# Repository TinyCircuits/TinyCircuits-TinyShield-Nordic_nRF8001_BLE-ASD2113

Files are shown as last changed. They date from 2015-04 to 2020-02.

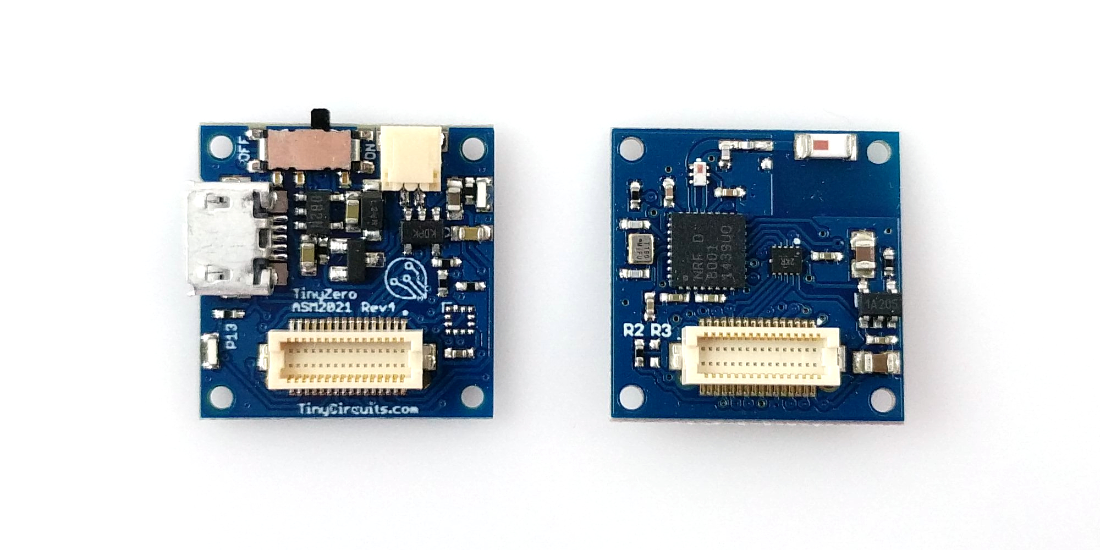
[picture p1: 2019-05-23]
images/ASD2113-R-Tutorial-Image-02.jpg

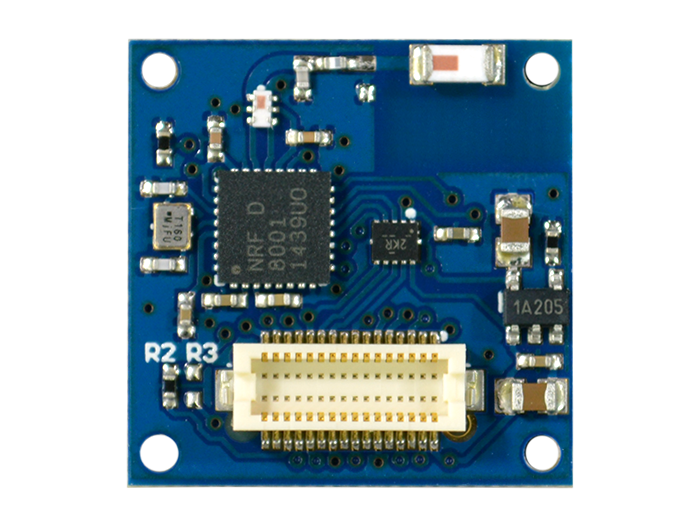
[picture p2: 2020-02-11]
images/ASD2113-R-Tutorial-Image-01.png

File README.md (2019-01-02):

# TinyCircuits TinyShield Nordic nRF8001 Bluetooth LE Board
# ASD2113 Rev3

The design files are located under design_files/ for the TinyCircuits ASD2113 Rev3 PCB.  This is a TinyShield board that has a Nordic Semiconductor nRF8001 Bluetooth Low Energy (or Smart) 4.0 chipset, local power supply and level shifters to connect between the TinyDuino and the Bluetooth LE Module. 

Format is in Cadsoft Eagle format - Eagle version 6.2 was used for the original design.

For more infomation on this, check out the product page at TinyCircuits.com: https://tinycircuits.com/collections/communication/products/bluetooth-low-energy-nordic-tinyshield

# License:

Design by TinyCircuits.
All design files are released under the Creative Commons Attribution Share-Alike 3.0 License, see the following link for details: http://creativecommons.org/licenses/by-sa/3.0

All text above must be included in any redistribution or derived design

This project uses designs and concepts developed as part of the Arduino project and the LilyPad project.  The TinyCircuits design files themselves (schematics, PCB and libraries) are not directly derived from these works' design files and have been created new, however the concepts and basic architecture behind the TinyDuino and TinyLily products are derived and we thank the hard work of the organizations below for their contributions to open-source hardware:
  
Original Arduino Uno Design by Team Arduino

LilyPad Arduino Design by Leah Buechley and Sparkfun Electronics

Please support the open-source hardware community

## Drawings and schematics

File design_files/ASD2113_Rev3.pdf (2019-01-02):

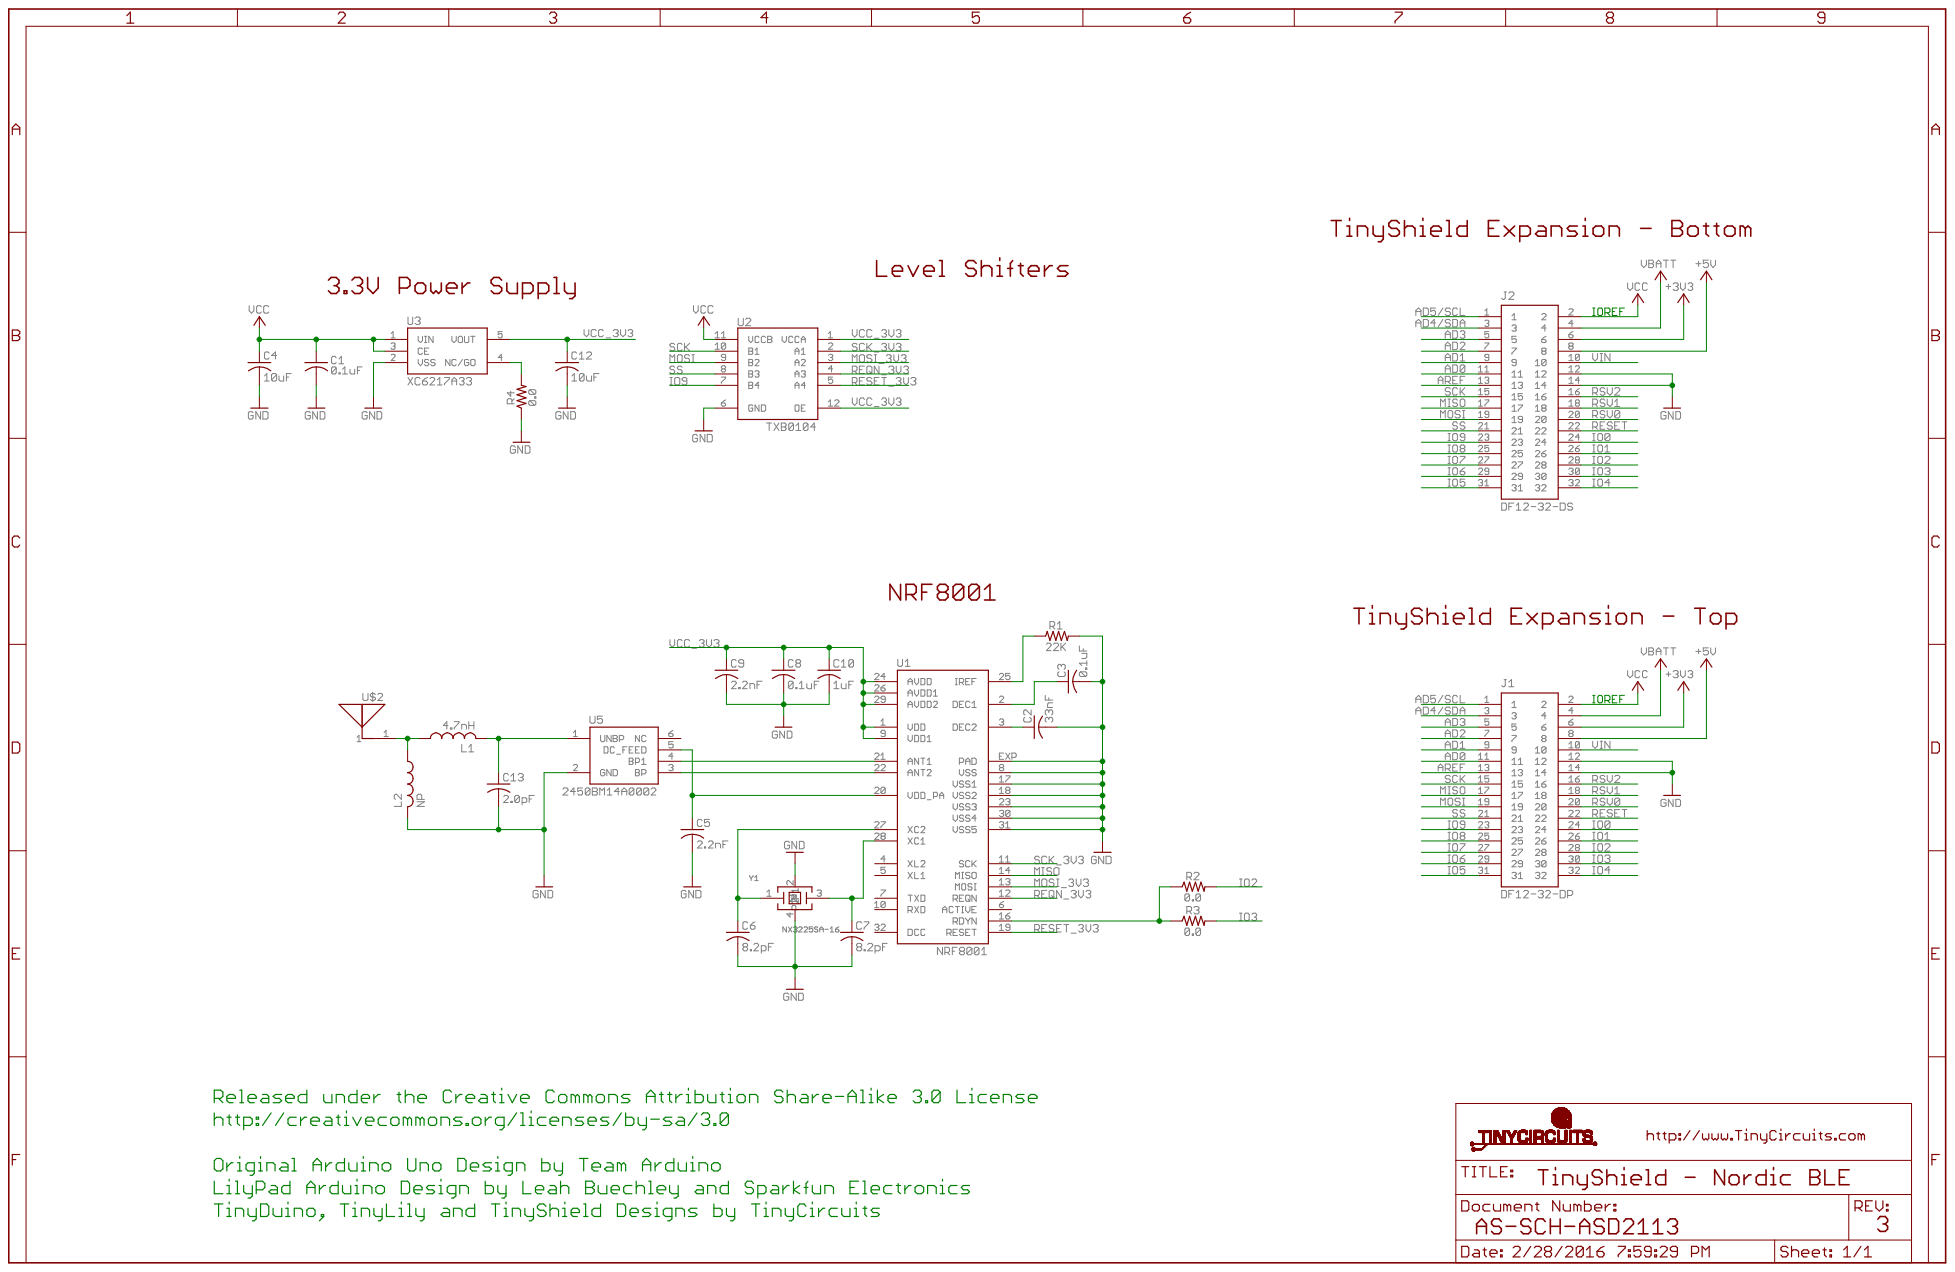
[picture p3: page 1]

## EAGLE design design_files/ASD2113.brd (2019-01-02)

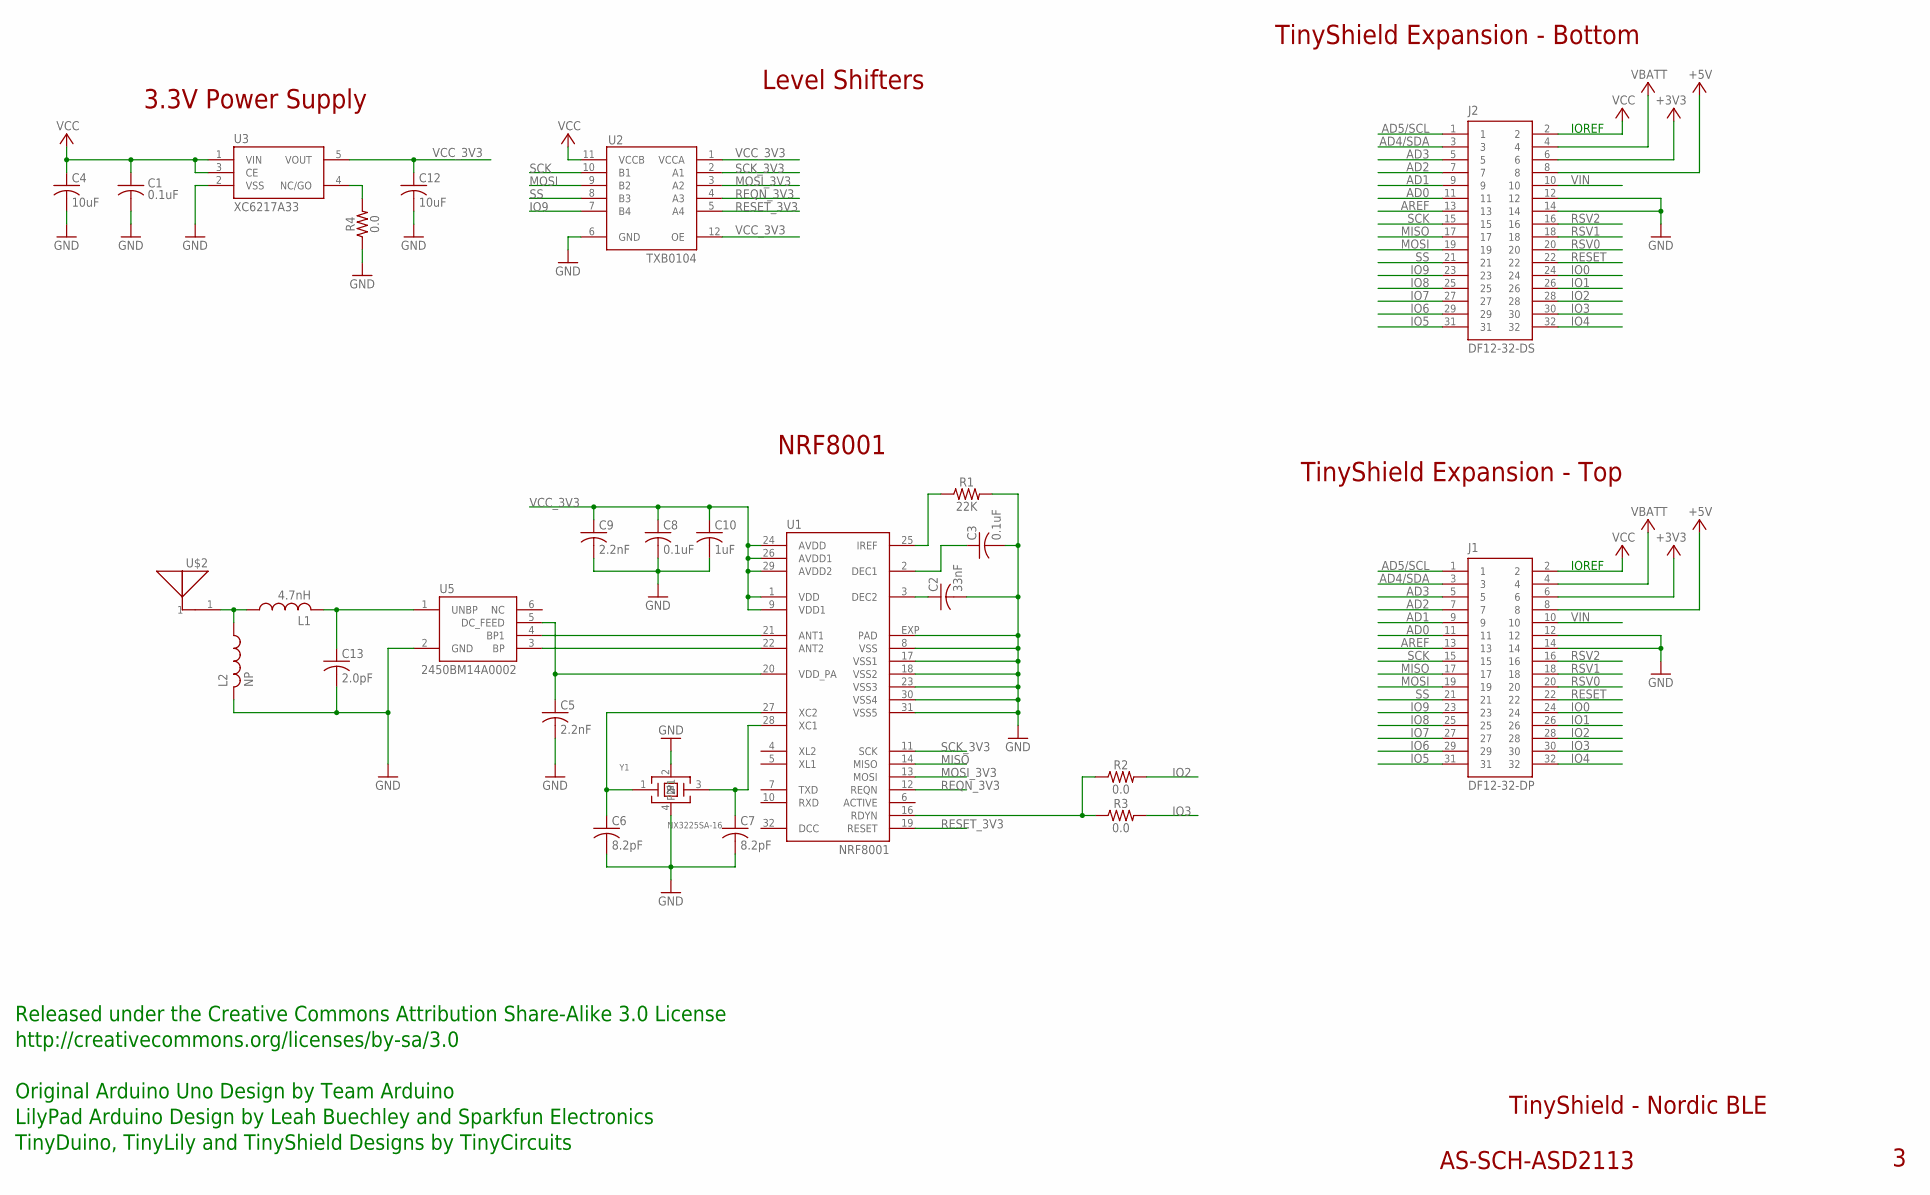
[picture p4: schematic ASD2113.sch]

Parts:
C1: 0.1uF; C0402; PARTNO AS-ITM-00008
C2: 33nF; C0402; PARTNO AS-ITM-00248
C3, C8: 0.1uF; C0402
C4, C12: 10uF; C0805; PARTNO AS-ITM-00045
C5, C9: 2.2nF; C0402
C6, C7: 8.2pF; C0402; PARTNO AS-ITM-00247
C10: 1uF; C0402
C13: 2.0pF; C0402; PARTNO AS-ITM-00245
J1: DF12-32-DP; PARTNO AS-ITM-00015
J2: DF12-32-DS; PARTNO AS-ITM-00012
L1: 4.7nH; C0402; PARTNO AS-ITM-00246
L2: NP; C0402
R1: 22K; 0402
R2, R3: 0.0; 0402; PARTNO AS-ITM-00076
R4: 0.0; 0402
U1: NRF8001; ATMEL_QFN32
U2: TXB0104; UQFN-12
U3: XC6217A33; SOT-25; PARTNO AS-ITM-00249
U5: 2450BM14A0002
U$2: AS-ITM-00132; 2450AT18A100; PARTNO AS-ITM-00132
Y1: NX3225SA-16; ABM11; PARTNO AS-ITM-00228

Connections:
+3V3: J1.6, J2.6
+5V: J1.8, J2.8
AD0: J1.11, J2.11
AD1: J1.9, J2.9
AD2: J1.7, J2.7
AD3: J1.5, J2.5
AD4/SDA: J1.3, J2.3
AD5/SCL: J1.1, J2.1
AREF: J1.13, J2.13
GND: C1.2, C2.2, C3.2, C4.2, C5.2, C6.2, C7.2, C8.2, C9.2, C10.2, C12.2, C13.2, J1.12, J1.14, J2.12, J2.14, L2.2, R1.2, R4.1, U1.8 (VSS), U1.17 (VSS1), U1.18 (VSS2), U1.23 (VSS3), U1.30 (VSS4), U1.31 (VSS5), U1.EXP (PAD), U2.6 (GND), U3.2 (VSS), U5.2 (GND), Y1.2, Y1.4 (P1)
IO0: J1.24, J2.24
IO1: J1.26, J2.26
IO2: J1.28, J2.28, R2.2
IO3: J1.30, J2.30, R3.2
IO4: J1.32, J2.32
IO5: J1.31, J2.31
IO6: J1.29, J2.29
IO7: J1.27, J2.27
IO8: J1.25, J2.25
IO9: J1.23, J2.23, U2.7 (B4)
MISO: J1.17, J2.17, U1.14 (MISO)
MOSI: J1.19, J2.19, U2.9 (B2)
MOSI_3V3: U1.13 (MOSI), U2.3 (A2)
unnamed: R1.1, U1.25 (IREF)
unnamed: C6.1, U1.27 (XC2), Y1.1
unnamed: C13.1, L1.2, U5.1 (UNBP)
unnamed: C3.1, U1.2 (DEC1)
unnamed: C2.1, U1.3 (DEC2)
unnamed: U1.22 (ANT2), U5.3 (BP)
unnamed: U1.21 (ANT1), U5.4 (BP1)
unnamed: C5.1, U1.20 (VDD_PA), U5.5 (DC_FEED)
unnamed: C7.1, U1.28 (XC1), Y1.3 (2)
unnamed: L1.1, L2.1, U$2.1
unnamed: R4.2, U3.4 (NC/GO)
RDYN: R2.1, R3.1, U1.16 (RDYN)
REQN_3V3: U1.12 (REQN), U2.4 (A3)
RESET: J1.22, J2.22
RESET_3V3: U1.19 (RESET), U2.5 (A4)
RSV0: J1.20, J2.20
RSV1: J1.18, J2.18
RSV2: J1.16, J2.16
SCK: J1.15, J2.15, U2.10 (B1)
SCK_3V3: U1.11 (SCK), U2.2 (A1)
SS: J1.21, J2.21, U2.8 (B3)
VBATT: J1.4, J2.4
VCC: C1.1, C4.1, J1.2, J2.2, U2.11 (VCCB), U3.1 (VIN), U3.3 (CE)
VCC_3V3: C8.1, C9.1, C10.1, C12.1, U1.1 (VDD), U1.9 (VDD1), U1.24 (AVDD), U1.26 (AVDD1), U1.29 (AVDD2), U2.1 (VCCA), U2.12 (OE), U3.5 (VOUT)
VIN: J1.10, J2.10

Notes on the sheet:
TinyShield Expansion - Bottom
TinyShield - Nordic BLE
AS-SCH-ASD2113
TinyShield Expansion - Top
IOREF
Released under the Creative Commons Attribution Share-Alike 3.0 License
http://creativecommons.org/licenses/by-sa/3.0
LilyPad Arduino Design by Leah Buechley and Sparkfun Electronics
TinyDuino, TinyLily and TinyShield Designs by TinyCircuits
Original Arduino Uno Design by Team Arduino
3.3V Power Supply
NRF8001
Level Shifters

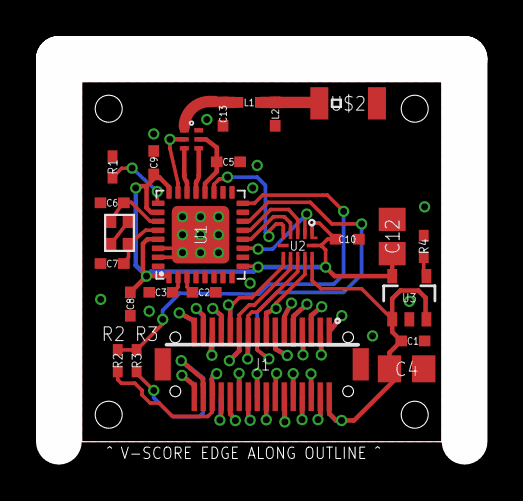
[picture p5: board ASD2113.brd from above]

Board: 2 copper layers, 20.0 x 20.0 mm, 27 parts (1 on the bottom side), 48 nets.

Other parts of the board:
U$1: DOCFIELD-TINYCIRCUITS-PCB

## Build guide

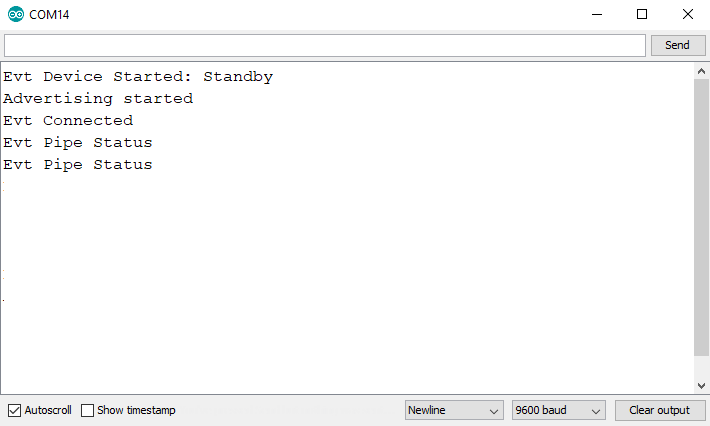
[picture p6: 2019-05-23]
images/ASD2113-R-Tutorial-Image-10.png

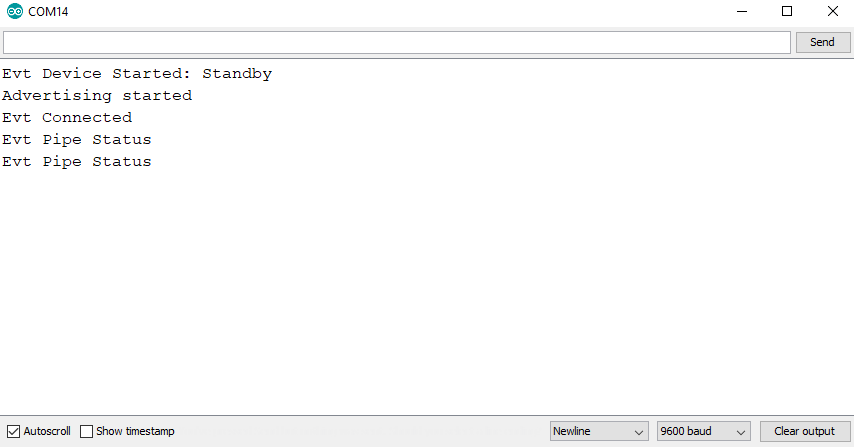
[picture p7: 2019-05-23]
images/ASD2113-R-Tutorial-Image-06.png

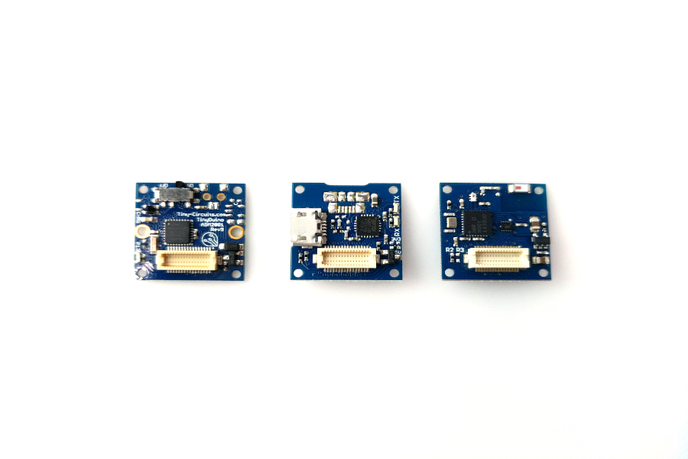
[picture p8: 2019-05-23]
images/ASD2113-R-Tutorial-Image-02.png

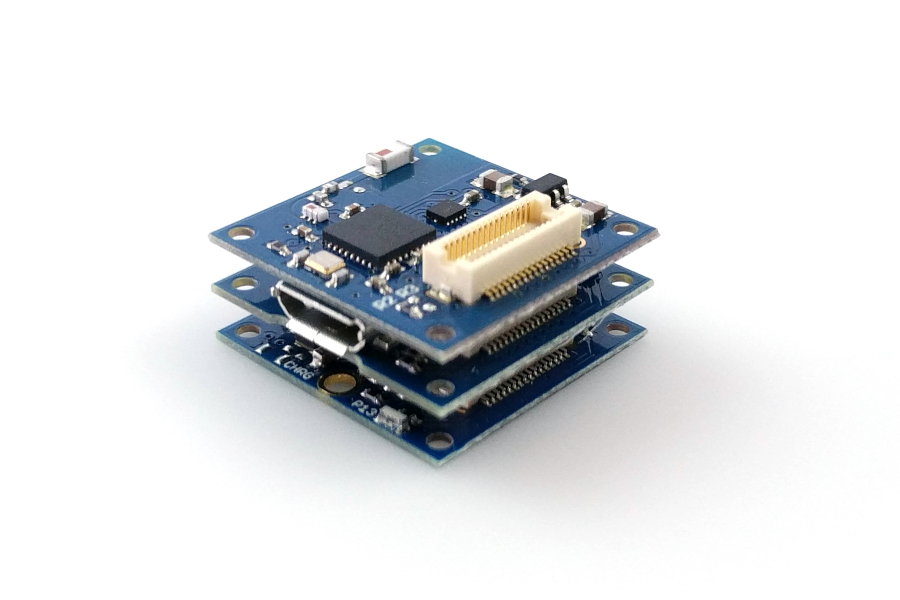
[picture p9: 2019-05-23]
images/ASD2113-R-Tutorial-Image-03.png

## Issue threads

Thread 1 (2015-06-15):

404 - PAGE NOT FOUND

malayli, 2015-06-15:
Hello,

This link returns a 404 error:

https://tiny-circuits.com/tiny-shield-nrf8001-bluetooth-low-energy.html

Best Regards,

Malik ALAYLI

TinyCircuits, 2015-06-15:
Thanks for noticing this, the link is fixed now.

malayli, 2015-06-19:
Ok I close the issue :)

Closed 2015-06-19.

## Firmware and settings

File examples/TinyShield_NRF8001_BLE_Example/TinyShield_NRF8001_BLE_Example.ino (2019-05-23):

/*
  TinyCircuits NRF8001 UART Example Sketch

  This demo sets up the NRF8001 for Nordic's BLE virtual UART connection, and
  can pass data between the Arduino serial monitor and Nordic nRF UART V2.0 app
  or another compatible BLE terminal. Now supports TinyScreen+/SAMD21 boards.

  Written 27 May 2016
  By Ben Rose
  Modified 07 January 2019
  By Hunter Hykes

  https://TinyCircuits.com
*/


#if defined(ARDUINO_ARCH_SAMD)
  #define SerialMonitorInterface SerialUSB
#else
  #define SerialMonitorInterface Serial
#endif

#define BLE_DEBUG true

#include <SPI.h>
#include "lib_aci.h"
#include "aci_setup.h"
#include "uart_over_ble.h"
#include "services.h"

uint8_t ble_rx_buffer[21];
uint8_t ble_rx_buffer_len = 0;
uint8_t ble_connection_state = false;

void setup(void)
{
  SerialMonitorInterface.begin(9600);
//  while (!SerialMonitorInterface);//Optional- On TinyScreen+/SAMD21 boards this will block until the serial monitor is opened
  delay(1000);
  BLEsetup();
}

void loop() {
  aci_loop();//Process any ACI commands or events from the NRF8001- main BLE handler, must run often. Keep main loop short.
  if (ble_rx_buffer_len) {//Check if data is available
    SerialMonitorInterface.print(ble_rx_buffer_len);
    SerialMonitorInterface.print(" : ");
    SerialMonitorInterface.println((char*)ble_rx_buffer);
    ble_rx_buffer_len = 0;//clear afer reading
  }
  if (SerialMonitorInterface.available()) {//Check if serial input is available to send
    delay(50);//should catch full input
    uint8_t sendBuffer[21];
    uint8_t sendLength = 0;
    while (SerialMonitorInterface.available() && sendLength < 19) {
      sendBuffer[sendLength] = SerialMonitorInterface.read();
      sendLength++;
    }
    if (SerialMonitorInterface.available()) {
      SerialMonitorInterface.print(F("Input truncated, dropped: "));
      while (SerialMonitorInterface.available()) {
        SerialMonitorInterface.write(SerialMonitorInterface.read());
      }
      SerialMonitorInterface.println();
    }
    sendBuffer[sendLength] = '\0'; //Terminate string
    sendLength++;
    if (!lib_aci_send_data(PIPE_UART_OVER_BTLE_UART_TX_TX, (uint8_t*)sendBuffer, sendLength))
    {
      SerialMonitorInterface.println(F("TX dropped!"));
    }
  }

}

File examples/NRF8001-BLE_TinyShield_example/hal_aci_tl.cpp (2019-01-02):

/* Copyright (c) 2014, Nordic Semiconductor ASA
 *
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
 * THE SOFTWARE IS PROVIDED "AS IS", WITHOUT WARRANTY OF ANY KIND, EXPRESS OR
 * IMPLIED, INCLUDING BUT NOT LIMITED TO THE WARRANTIES OF MERCHANTABILITY,
 * FITNESS FOR A PARTICULAR PURPOSE AND NONINFRINGEMENT. IN NO EVENT SHALL THE
 * AUTHORS OR COPYRIGHT HOLDERS BE LIABLE FOR ANY CLAIM, DAMAGES OR OTHER
 * LIABILITY, WHETHER IN AN ACTION OF CONTRACT, TORT OR OTHERWISE, ARISING FROM,
 * OUT OF OR IN CONNECTION WITH THE SOFTWARE OR THE USE OR OTHER DEALINGS IN THE
 * SOFTWARE.
 */

/** @file
@brief Implementation of the ACI transport layer module
*/

#include <SPI.h>
#include "hal_platform.h"
#include "hal_aci_tl.h"
#include "aci_queue.h"
#if ( !defined(__SAM3X8E__) && !defined(__PIC32MX__) && !defined(ARDUINO_ARCH_SAMD))
#include <avr/sleep.h>
#endif
/*
PIC32 supports only MSbit transfer on SPI and the nRF8001 uses LSBit
Use the REVERSE_BITS macro to convert from MSBit to LSBit
The outgoing command and the incoming event needs to be converted
*/
//Board dependent defines
#if defined (__AVR__)
    //For Arduino add nothing
#elif defined(ARDUINO_ARCH_SAMD)
    //For Arduino add nothing
#elif defined(__PIC32MX__)
    //For ChipKit as the transmission has to be reversed, the next definitions have to be added
    #define REVERSE_BITS(byte) (((reverse_lookup[(byte & 0x0F)]) << 4) + reverse_lookup[((byte & 0xF0) >> 4)])
    static const uint8_t reverse_lookup[] = { 0, 8,  4, 12, 2, 10, 6, 14,1, 9, 5, 13,3, 11, 7, 15 };
#endif

static void m_aci_data_print(hal_aci_data_t *p_data);
static void m_aci_event_check(void);
static void m_aci_isr(void);
static void m_aci_pins_set(aci_pins_t *a_pins_ptr);
static inline void m_aci_reqn_disable (void);
static inline void m_aci_reqn_enable (void);
static void m_aci_q_flush(void);
static bool m_aci_spi_transfer(hal_aci_data_t * data_to_send, hal_aci_data_t * received_data);

static uint8_t        spi_readwrite(uint8_t aci_byte);

//static bool           aci_debug_print = false;

#define aci_debug_print false

aci_queue_t    aci_tx_q;
aci_queue_t    aci_rx_q;

static aci_pins_t	 *a_pins_local_ptr;

void m_aci_data_print(hal_aci_data_t *p_data)
{
  const uint8_t length = p_data->buffer[0];
  uint8_t i;
  Serial.print(length, DEC);
  Serial.print(" :");
  for (i=0; i<=length; i++)
  {
    Serial.print(p_data->buffer[i], HEX);
    Serial.print(F(", "));
  }
  Serial.println(F(""));
}

/*
  Interrupt service routine called when the RDYN line goes low. Runs the SPI transfer.
*/
static void m_aci_isr(void)
{
  hal_aci_data_t data_to_send;
  hal_aci_data_t received_data;

  // Receive from queue
  if (!aci_queue_dequeue_from_isr(&aci_tx_q, &data_to_send))
  {
    /* queue was empty, nothing to send */
    data_to_send.status_byte = 0;
    data_to_send.buffer[0] = 0;
  }

  // Receive and/or transmit data
  m_aci_spi_transfer(&data_to_send, &received_data);

  if (!aci_queue_is_full_from_isr(&aci_rx_q) && !aci_queue_is_empty_from_isr(&aci_tx_q))
  {
    m_aci_reqn_enable();
  }

  // Check if we received data
  if (received_data.buffer[0] > 0)
  {
    if (!aci_queue_enqueue_from_isr(&aci_rx_q, &received_data))
    {
      /* Receive Buffer full.
         Should never happen.
         Spin in a while loop.
      */
      while(1);
    }

    // Disable ready line interrupt until we have room to store incoming messages
    if (aci_queue_is_full_from_isr(&aci_rx_q))
    {
      detachInterrupt(a_pins_local_ptr->interrupt_number);
    }
  }

  return;
}

/*
  Checks the RDYN line and runs the SPI transfer if required.
*/
static void m_aci_event_check(void)
{
  hal_aci_data_t data_to_send;
  hal_aci_data_t received_data;

  // No room to store incoming messages
  if (aci_queue_is_full(&aci_rx_q))
  {
    return;
  }

  // If the ready line is disabled and we have pending messages outgoing we enable the request line
  if (HIGH == digitalRead(a_pins_local_ptr->rdyn_pin))
  {
    if (!aci_queue_is_empty(&aci_tx_q))
    {
      m_aci_reqn_enable();
    }

    return;
  }

  // Receive from queue
  if (!aci_queue_dequeue(&aci_tx_q, &data_to_send))
  {
    /* queue was empty, nothing to send */
    data_to_send.status_byte = 0;
    data_to_send.buffer[0] = 0;
  }

  // Receive and/or transmit data
  m_aci_spi_transfer(&data_to_send, &received_data);

  /* If there are messages to transmit, and we can store the reply, we request a new transfer */
  if (!aci_queue_is_full(&aci_rx_q) && !aci_queue_is_empty(&aci_tx_q))
  {
    m_aci_reqn_enable();
  }

  // Check if we received data
  if (received_data.buffer[0] > 0)
  {
    if (!aci_queue_enqueue(&aci_rx_q, &received_data))
    {
      /* Receive Buffer full.
         Should never happen.
         Spin in a while loop.
      */
      while(1);
    }
  }

  return;
}

/** @brief Point the low level library at the ACI pins specified
 *  @details
 *  The ACI pins are specified in the application and a pointer is made available for
 *  the low level library to use
 */
static void m_aci_pins_set(aci_pins_t *a_pins_ptr)
{
  a_pins_local_ptr = a_pins_ptr;
}

static inline void m_aci_reqn_disable (void)
{
  digitalWrite(a_pins_local_ptr->reqn_pin, 1);
}

static inline void m_aci_reqn_enable (void)
{
  digitalWrite(a_pins_local_ptr->reqn_pin, 0);
}

static void m_aci_q_flush(void)
{
  noInterrupts();
  /* re-initialize aci cmd queue and aci event queue to flush them*/
  aci_queue_init(&aci_tx_q);
  aci_queue_init(&aci_rx_q);
  interrupts();
}

static bool m_aci_spi_transfer(hal_aci_data_t * data_to_send, hal_aci_data_t * received_data)
{
  uint8_t byte_cnt;
  uint8_t byte_sent_cnt;
  uint8_t max_bytes;

  m_aci_reqn_enable();

  // Send length, receive header
  byte_sent_cnt = 0;
  received_data->status_byte = spi_readwrite(data_to_send->buffer[byte_sent_cnt++]);
  // Send first byte, receive length from slave
  received_data->buffer[0] = spi_readwrite(data_to_send->buffer[byte_sent_cnt++]);
  if (0 == data_to_send->buffer[0])
  {
    max_bytes = received_data->buffer[0];
  }
  else
  {
    // Set the maximum to the biggest size. One command byte is already sent
    max_bytes = (received_data->buffer[0] > (data_to_send->buffer[0] - 1))
                                          ? received_data->buffer[0]
                                          : (data_to_send->buffer[0] - 1);
  }

  if (max_bytes > HAL_ACI_MAX_LENGTH)
  {
    max_bytes = HAL_ACI_MAX_LENGTH;
  }

  // Transmit/receive the rest of the packet
  for (byte_cnt = 0; byte_cnt < max_bytes; byte_cnt++)
  {
    received_data->buffer[byte_cnt+1] =  spi_readwrite(data_to_send->buffer[byte_sent_cnt++]);
  }

  // RDYN should follow the REQN line in approx 100ns
  m_aci_reqn_disable();

  return (max_bytes > 0);
}

void hal_aci_tl_debug_print(bool enable)
{
	//aci_debug_print = enable;
}
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
